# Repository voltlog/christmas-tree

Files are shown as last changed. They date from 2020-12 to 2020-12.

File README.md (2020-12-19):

# Voltlog Smart Christmas Tree

This was my attempt at creating a smart Christmass tree decoration. I wanted to have a bunch of RGB LEDs that I could control remotely from my smart home automation system so I created this board using 11 x SK6812-EC20 RGB LEDs connected with an ESP32. The board can be flashed with an arduino sketch and have it flash various patterns in a standalone operating mode or you can flash it with esphome (or other similar platforms) and have it controlled from your smart home system.

More info about this project in [Voltlog #344](https://youtu.be/laZLzfCeY8s).
This was available in a limitted edition in the [Voltlog Tindie Store](https://www.tindie.com/products/voltlog/voltlog-smart-christmas-tree/).

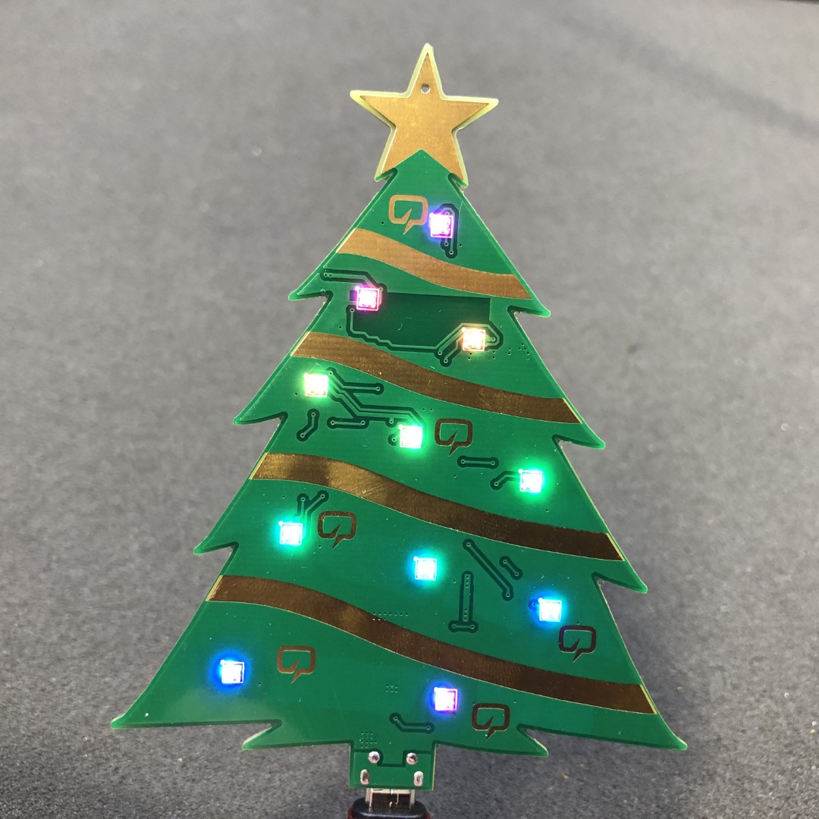
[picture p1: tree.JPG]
Image of the bulb


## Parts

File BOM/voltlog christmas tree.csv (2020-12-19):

Component Count: | 49
Ref | Qnty | Value | Cmp name | Footprint | Description
C1, C2, C3, C4, C6, C7, C8, C9, C10, C11, C13, C14, | 12 | 0.1uF | C_Small | Capacitor_SMD:C_0805_2012Metric | Unpolarized capacitor, small symbol
C12, | 1 | 22uF | C_Small | Capacitor_SMD:C_0805_2012Metric | Unpolarized capacitor, small symbol
C15, C16 | 1 | 10uF, 16V | C_Small | Capacitor_SMD:C_0805_2012Metric | Unpolarized capacitor, small symbol
D1, D2, D3, D4, D5, D6, D7, D8, D9, D10, D11, | 11 | SK6812MINI | SK6812MINI | Voltlog:sk6812-2020 | RGB LED with integrated controller
D12, | 1 | LED | LED | LED_SMD:LED_0805_2012Metric | Light emitting diode
F1, | 1 | 0.75A | Polyfuse | Fuse:Fuse_0805_2012Metric | Resettable fuse, polymeric positive temperature coefficient
J1, | 1 | Conn_01x06 | Conn_01x06 | Connector_JST:JST_SH_BM06B-SRSS-TB_1x06-1MP_P1.00mm_Vertical | Generic connector, single row, 01x06, script generated (kicad-library-utils/schlib/autogen/connector/)
J2, | 1 | USB_B_Micro | USB_B_Micro | Connector_USB:USB_Micro-B_Molex-105017-0001 | USB Micro Type B connector
JP1, | 1 | NO | SolderJumper_2_Open | Jumper:SolderJumper-2_P1.3mm_Open_RoundedPad1.0x1.5mm | Solder Jumper, 2-pole, open
Q1, | 1 | 2N7002 | 2N7002 | Package_TO_SOT_SMD:SOT-23 | 0.115A Id, 60V Vds, N-Channel MOSFET, SOT-23
R1, R2, R3, R5, | 4 | 10K | R_US | Resistor_SMD:R_0805_2012Metric | Resistor, US symbol
R4, R6, | 2 | 1K | R_US | Resistor_SMD:R_0805_2012Metric | Resistor, US symbol
SW1, | 1 | SW_Push | SW_Push | Button_Switch_SMD:SW_Push_1P1T_NO_6x6mm_H9.5mm | Push button switch, generic, two pins
T1, | 1 | ChristmasTree | ChristmasTree | Voltlog:test | Christmas tree symbol
U1, | 1 | ESP32-WROOM-32D | ESP32-WROOM-32D | RF_Module:ESP32-WROOM-32 | RF Module, ESP32-D0WD SoC, Wi-Fi 802.11b/g/n, Bluetooth, BLE, 32-bit, 2.7-3.6V, onboard antenna, SMD
U2, | 1 | NCP1117-3.3_SOT223 | NCP1117-3.3_SOT223 | Package_TO_SOT_SMD:SOT-223-3_TabPin2 | 1A Low drop-out regulator, Fixed Output 3.3V, SOT-223
V1, V2, V3, V4, V5, V6, V8, | 7 | VOLTLOG_LOGO | VOLTLOG_LOGO | Voltlog:voltlog_mask_5mm

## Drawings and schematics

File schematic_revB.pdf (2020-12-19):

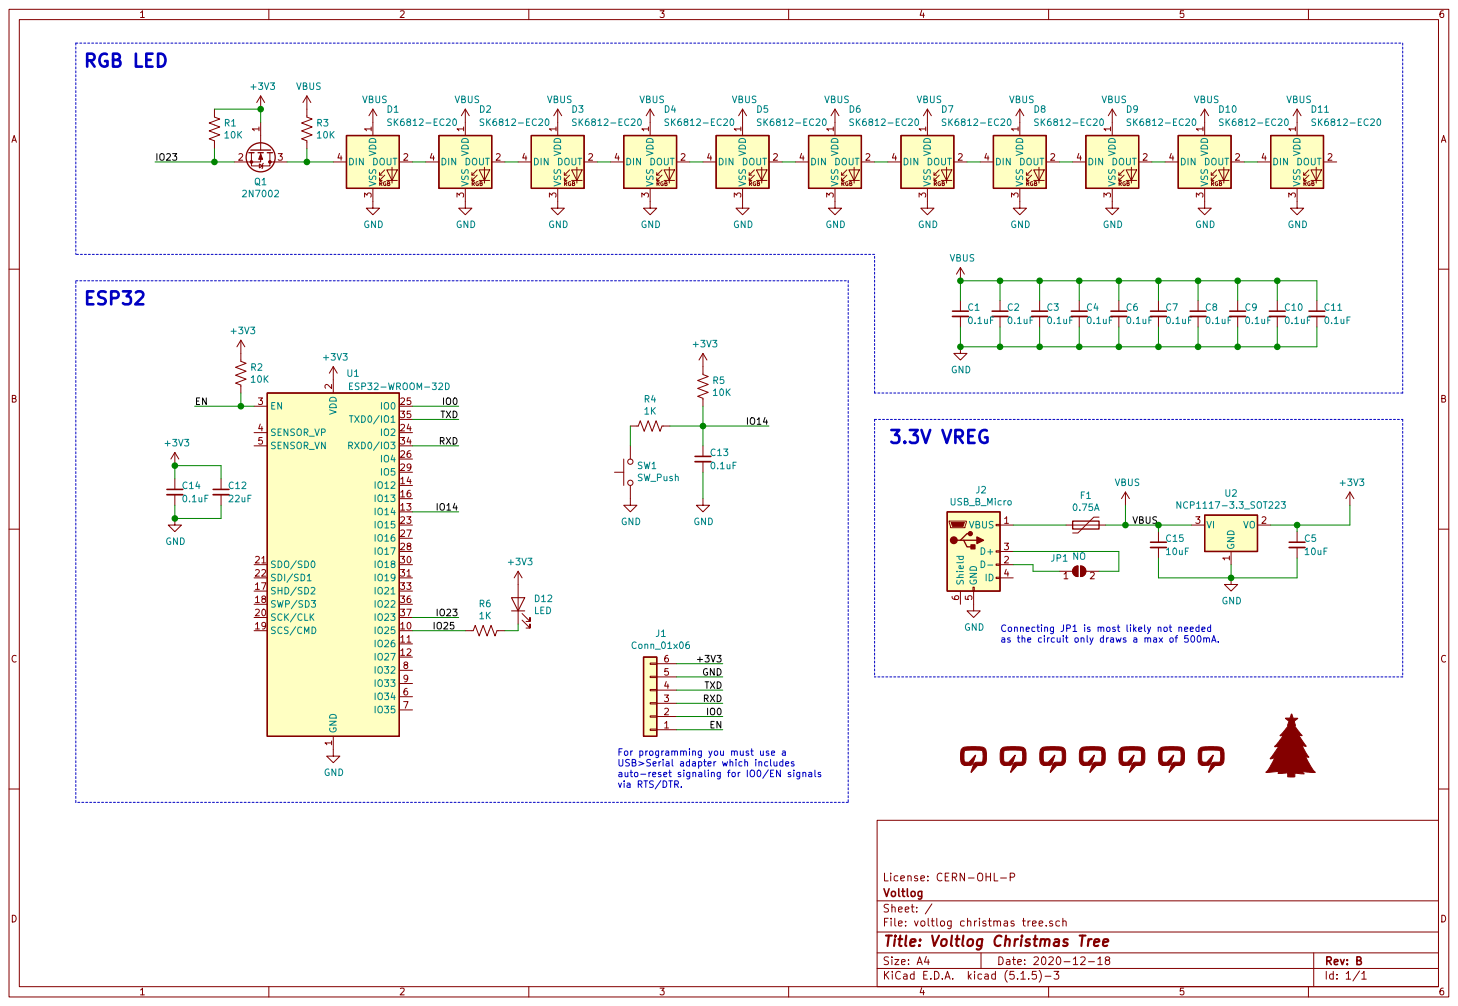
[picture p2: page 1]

auto-reset signaling for IO0/EN signals via RTS/DTR. RGB LED

2 SCK/CLK 20 SDO/SD0 21 SDI/SD1 22

Connecting JP1 is most likely not needed
as the circuit only draws a max of 500mA.

For programming you must use a
USB>Serial adapter which includes

License: CERN-OHL-P
File: voltlog christmas tree.sch Sheet: / Voltlog

Id: 1/1 Title: Voltlog Christmas Tree

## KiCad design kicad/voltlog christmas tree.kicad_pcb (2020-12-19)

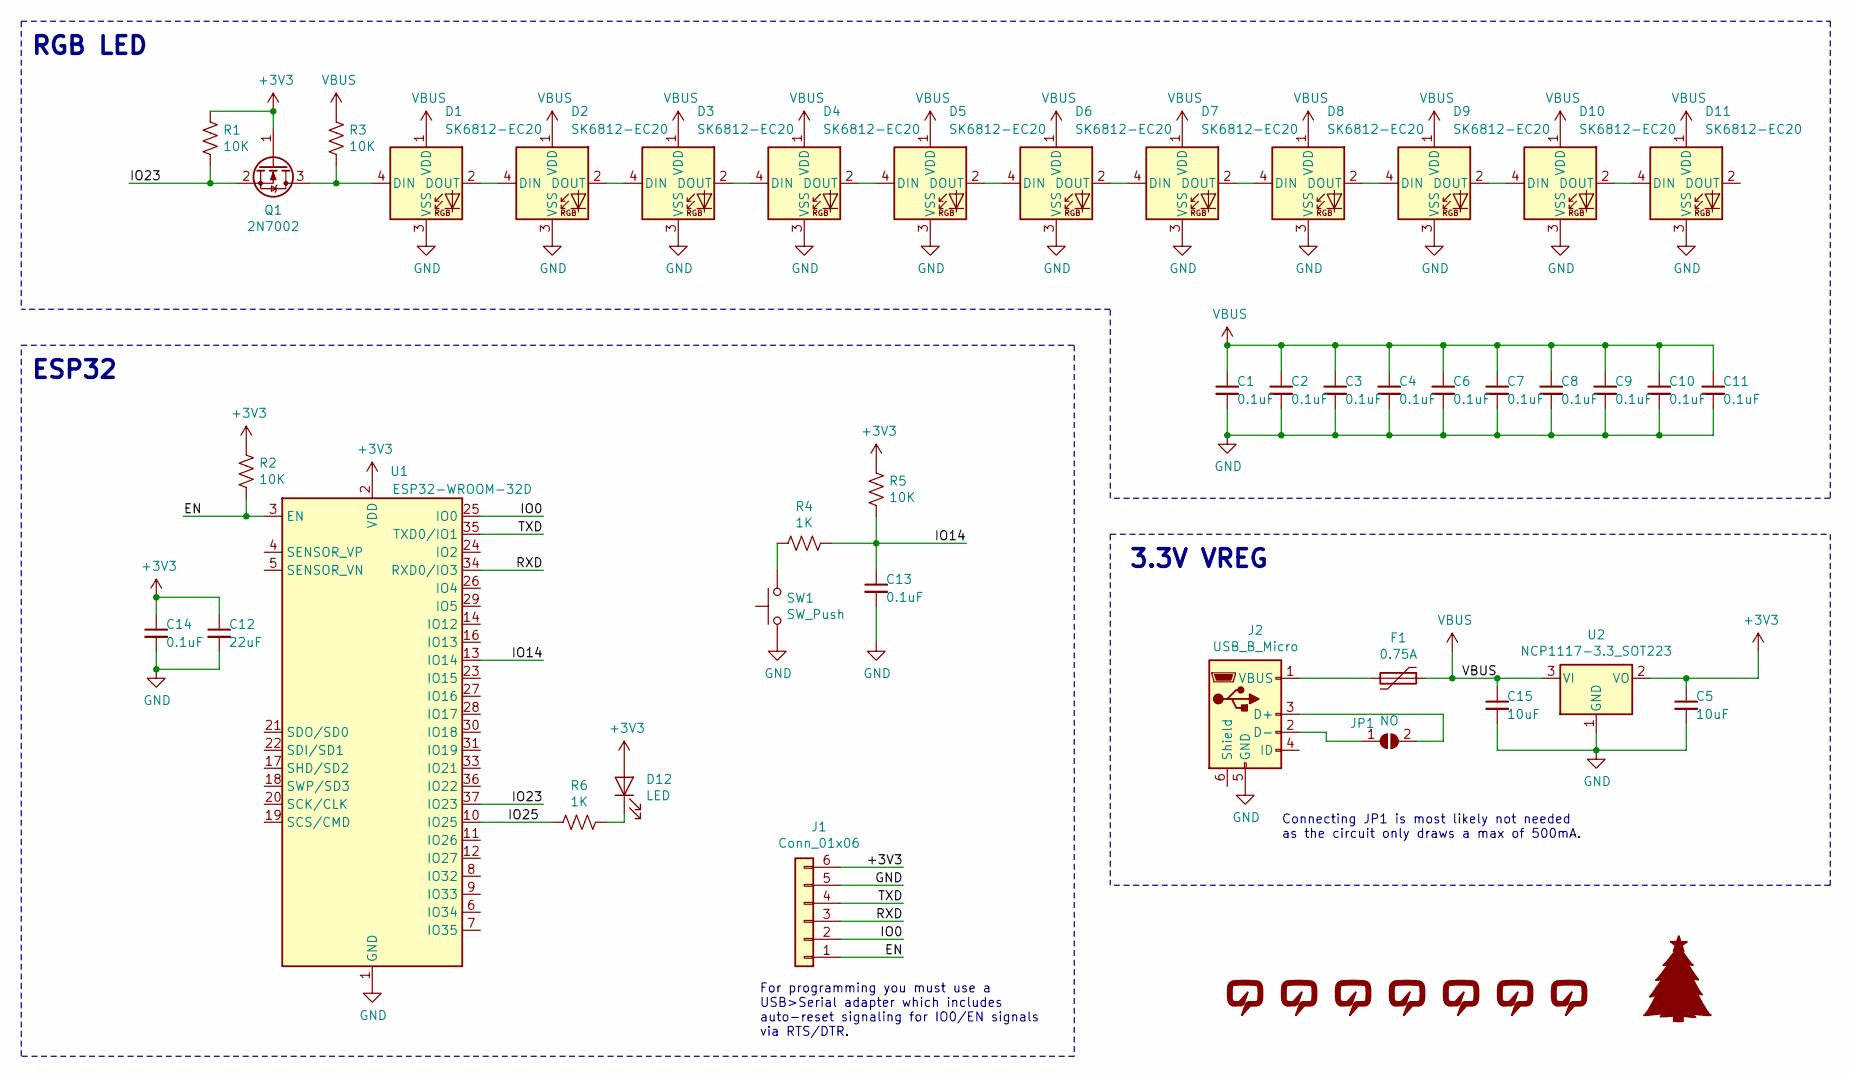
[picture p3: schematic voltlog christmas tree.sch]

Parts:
C1, C2, C3, C4, C6, C7, C8, C9, C10, C11, C13, C14: 0.1uF; C_0805_2012Metric
C5, C15: 10uF; C_0805_2012Metric
C12: 22uF; C_0805_2012Metric
D1, D2, D3, D4, D5, D6, D7, D8, D9, D10, D11: SK6812-EC20; sk6812-2020
D12: LED; LED_0805_2012Metric
F1: 0.75A; Fuse_0805_2012Metric
J1: Conn_01x06; JST_SH_BM06B-SRSS-TB_1x06-1MP_P1.00mm_Vertical
J2: USB_B_Micro; USB_Micro-B_Molex-105017-0001
JP1: NO; SolderJumper-2_P1.3mm_Open_RoundedPad1.0x1.5mm
Q1: 2N7002; SOT-23
R1, R2, R3, R5: 10K; R_0805_2012Metric
R4, R6: 1K; R_0805_2012Metric
SW1: SW_Push; SW_Push_1P1T_NO_6x6mm_H9.5mm
T1: ChristmasTree; test
U1: ESP32-WROOM-32D; ESP32-WROOM-32
U2: NCP1117-3.3_SOT223; SOT-223-3_TabPin2
V1, V2, V3, V4, V5, V6, V8: VOLTLOG_LOGO; voltlog_mask_5mm

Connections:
+3V3: C5.1, C12.1, C14.1, D12.2 (A), J1.6, Q1.1 (G), R1.1, R2.1, R5.1, U1.2 (VDD), U2.2 (VO)
/EN: J1.1, R2.2, U1.3 (EN)
/IO0: J1.2, U1.25 (IO0)
/IO14: C13.1, R4.1, R5.2, U1.13 (IO14)
/IO23: Q1.2 (S), R1.2, U1.37 (IO23)
/IO25: R6.2, U1.10 (IO25)
/RXD: J1.3, U1.34 (RXD0/IO3)
/TXD: J1.4, U1.35 (TXD0/IO1)
GND: C1.2, C2.2, C3.2, C4.2, C5.2, C6.2, C7.2, C8.2, C9.2, C10.2, C11.2, C12.2, C13.2, C14.2, C15.2, D1.3 (VSS), D2.3 (VSS), D3.3 (VSS), D4.3 (VSS), D5.3 (VSS), D6.3 (VSS), D7.3 (VSS), D8.3 (VSS), D9.3 (VSS), D10.3 (VSS), D11.3 (VSS), J1.5, J2.5 (GND), SW1.1, U1.1 (GND), U1.15 (GND), U1.38 (GND), U1.39 (GND), U2.1 (GND)
unnamed: D1.2 (DOUT), D2.4 (DIN)
unnamed: D1.4 (DIN), Q1.3 (D), R3.2
unnamed: D2.2 (DOUT), D3.4 (DIN)
unnamed: D3.2 (DOUT), D4.4 (DIN)
unnamed: D4.2 (DOUT), D5.4 (DIN)
unnamed: D5.2 (DOUT), D6.4 (DIN)
unnamed: D6.2 (DOUT), D7.4 (DIN)
unnamed: D7.2 (DOUT), D8.4 (DIN)
unnamed: D8.2 (DOUT), D9.4 (DIN)
unnamed: D10.2 (DOUT), D11.4 (DIN)
unnamed: D9.2 (DOUT), D10.4 (DIN)
unnamed: D12.1 (K), R6.1
unnamed: F1.2, J2.1 (VBUS)
unnamed: J2.2 (D-), JP1.1 (A)
unnamed: J2.3 (D+), JP1.2 (B)
unnamed: R4.2, SW1.2
VBUS: C1.1, C2.1, C3.1, C4.1, C6.1, C7.1, C8.1, C9.1, C10.1, C11.1, C15.1, D1.1 (VDD), D2.1 (VDD), D3.1 (VDD), D4.1 (VDD), D5.1 (VDD), D6.1 (VDD), D7.1 (VDD), D8.1 (VDD), D9.1 (VDD), D10.1 (VDD), D11.1 (VDD), F1.1, R3.1, U2.3 (VI)

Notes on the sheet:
ESP32
3.3V VREG
RGB LED
For programming you must use a USB>Serial adapter which includes auto-reset signaling for IO0/EN signals via RTS/DTR.
Connecting JP1 is most likely not needed as the circuit only draws a max of 500mA.

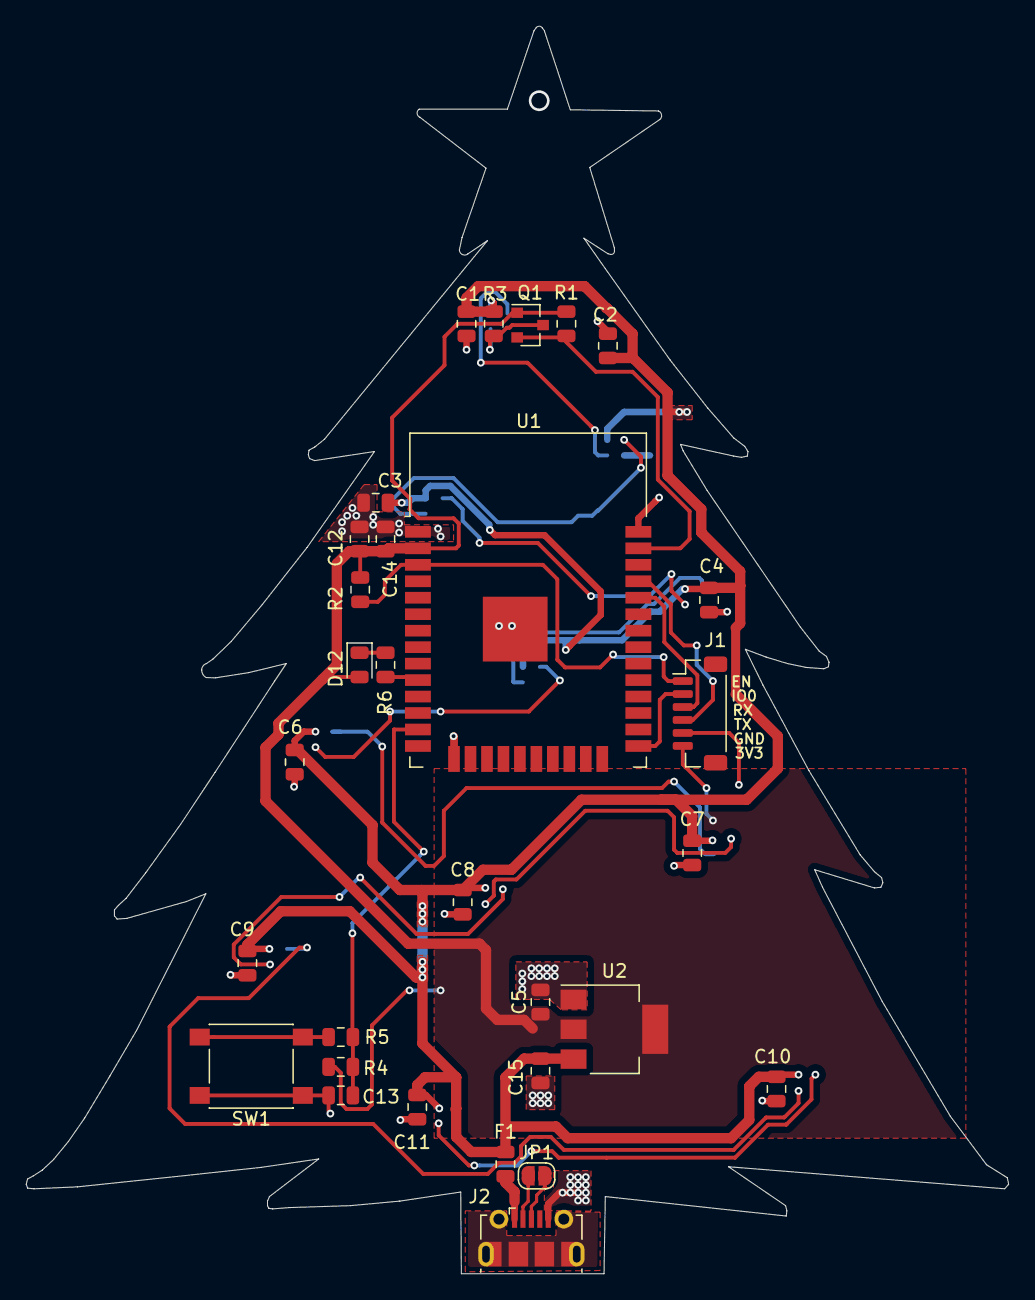
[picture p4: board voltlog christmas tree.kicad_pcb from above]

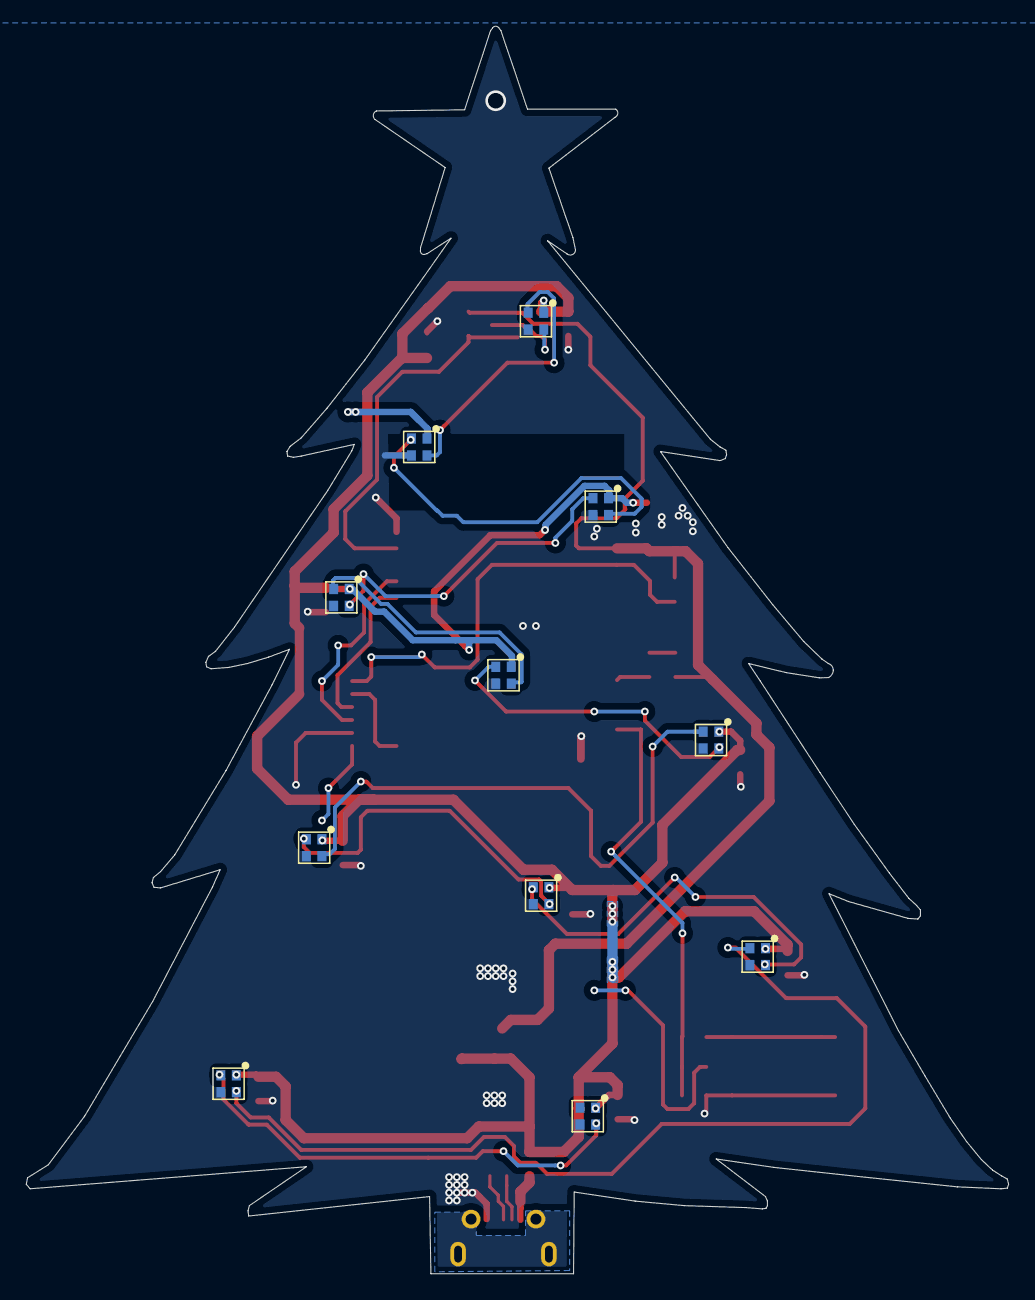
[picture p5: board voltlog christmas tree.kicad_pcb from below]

Board: 2 copper layers, 75.8 x 96.2 mm, 49 parts (17 on the bottom side), 26 nets.

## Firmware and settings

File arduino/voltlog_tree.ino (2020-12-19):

#include <Adafruit_NeoPixel.h>


#define STATUS_LED 25
#define RGB_LED 23
#define RGB_LED_PIXELS 11
#define SWITCH 14
volatile byte brightness = 32; //  default brightness 25 (from 0 -255)



// Parameter 1 = number of pixels in strip
// Parameter 2 = Arduino pin number (most are valid)
// Parameter 3 = pixel type flags, add together as needed:
Adafruit_NeoPixel strip = Adafruit_NeoPixel(RGB_LED_PIXELS, RGB_LED, NEO_GRB + NEO_KHZ800);

void IRAM_ATTR isr() {
  brightness += 32;
  strip.setBrightness(brightness);
  Serial.print("Brightness set to ");
  Serial.print(brightness);
  Serial.println();
}

void setup() {
  // Give some time to open serial monitor after programming
  delay(1000);
  
  Serial.begin(115200);
  while (!Serial); // wait for serial attach
  
  Serial.println();
  Serial.println("Voltlog systems initializing...");

  pinMode(SWITCH, INPUT_PULLUP);
  attachInterrupt(SWITCH, isr, FALLING);  //attach interrupt to switch pin
  
  strip.begin();
  strip.setBrightness(brightness);
  Serial.println("Brightness set to default value of 25");
  strip.show(); // Initialize all pixels to 'off'

  Serial.println("System ready...");
}

void loop() {
  // Some example procedures showing how to display to the pixels:
  Serial.println("RED");
  colorWipe(strip.Color(255, 0, 0), 100); // Red
  Serial.println("GREEN");
  colorWipe(strip.Color(0, 255, 0), 100); // Green
  Serial.println("BLUE");
  colorWipe(strip.Color(0, 0, 255), 100); // Blue

  // Send a theater pixel chase in...
  Serial.println("Pixel chase WHITE");
  //theaterChase(strip.Color(127, 127, 127), 50); // White
  Serial.println("Pixel chase RED");
  //theaterChase(strip.Color(127, 0, 0), 50); // Red
  Serial.println("Pixel chase Blue");
  //theaterChase(strip.Color(0, 0, 127), 50); // Blue

  Serial.println("Rainbow");
  //rainbow(20);
  Serial.println("Rainbow cycle");
  //rainbowCycle(20);
  //Serial.println("Rainbow chase");
  //theaterChaseRainbow(75);
}


// Fill the dots one after the other with a color
void colorWipe(uint32_t c, uint8_t wait) {
  for(uint16_t i=0; i<strip.numPixels(); i++) {
    strip.setPixelColor(i, c);
    strip.show();
    delay(wait);
  }
}

void rainbow(uint8_t wait) {
  uint16_t i, j;

  for(j=0; j<256; j++) {
    for(i=0; i<strip.numPixels(); i++) {
      strip.setPixelColor(i, Wheel((i+j) & 255));
    }
    strip.show();
    delay(wait);
  }
}

// Slightly different, this makes the rainbow equally distributed throughout
void rainbowCycle(uint8_t wait) {
  uint16_t i, j;

  for(j=0; j<256*5; j++) { // 5 cycles of all colors on wheel
    for(i=0; i< strip.numPixels(); i++) {
      strip.setPixelColor(i, Wheel(((i * 256 / strip.numPixels()) + j) & 255));
    }
    strip.show();
    delay(wait);
  }
}

//Theatre-style crawling lights.
void theaterChase(uint32_t c, uint8_t wait) {
  for (int j=0; j<10; j++) {  //do 10 cycles of chasing
    for (int q=0; q < 3; q++) {
      for (uint16_t i=0; i < strip.numPixels(); i=i+3) {
        strip.setPixelColor(i+q, c);    //turn every third pixel on
      }
      strip.show();

      delay(wait);

      for (uint16_t i=0; i < strip.numPixels(); i=i+3) {
        strip.setPixelColor(i+q, 0);        //turn every third pixel off
      }
    }
  }
}

//Theatre-style crawling lights with rainbow effect
void theaterChaseRainbow(uint8_t wait) {
  for (int j=0; j < 256; j++) {     // cycle all 256 colors in the wheel
    for (int q=0; q < 3; q++) {
      for (uint16_t i=0; i < strip.numPixels(); i=i+3) {
        strip.setPixelColor(i+q, Wheel( (i+j) % 255));    //turn every third pixel on
      }
      strip.show();

      delay(wait);

      for (uint16_t i=0; i < strip.numPixels(); i=i+3) {
        strip.setPixelColor(i+q, 0);        //turn every third pixel off
      }
    }
  }
}

// Input a value 0 to 255 to get a color value.
// The colours are a transition r - g - b - back to r.
uint32_t Wheel(byte WheelPos) {
  WheelPos = 255 - WheelPos;
  if(WheelPos < 85) {
    return strip.Color(255 - WheelPos * 3, 0, WheelPos * 3);
  }
  if(WheelPos < 170) {
    WheelPos -= 85;
    return strip.Color(0, WheelPos * 3, 255 - WheelPos * 3);
  }
  WheelPos -= 170;
  return strip.Color(WheelPos * 3, 255 - WheelPos * 3, 0);
}
